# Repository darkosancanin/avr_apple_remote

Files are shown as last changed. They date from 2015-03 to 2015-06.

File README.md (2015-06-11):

### Overview 
ATtiny85 based micro controller project that replicates the functionality of an Apple remote control along with a simple hardware design for the remote control.

### Apple Remote/ NEC Protocol Overview
- The Apple Remote uses an NEC IR protocol which consists of a differential PPM encoding on a 1:3 duty cycle 38 kHz 950 nm infrared carrier.
- Remote commands are 32 bits long, in the format : remote id (8bits), command (8 bits), apple identifier (16 bits)
- The 32 bits of encoded data are sent between the leader and the stop bit (time in microseconds):
  - leader: 9000 on, 4500 off
  - 0 bit: 560 on, 1690 off
  - 1 bit: 560 on, 565 off
  - stop: 560 on
- More information at http://en.wikipedia.org/wiki/Apple_Remote and http://www.sbprojects.com/knowledge/ir/nec.php

### Implementation Overview
- This code uses a 50% duty cycle for the PWM (instead of the standard 1:3) for simplicity which still works.
- PWM is done using 'Clear Timer on Compare Match (CTC) Mode'. [Page 72] 11.7.2 describes CTC mode.
- Output is on 0C0A which is PB0. The internal clock is set to run at 8Mhz.
- No prescaler is used. @8Mhz 1 tick = .000000125 secs, 38khz is a cycle every .000026 secs. 
- This means there is 208 ticks required for a full cycle (.000026/.000000125). OCR0A is set to half of this at 104.
- This is half a full cycle, meaning it will be off for a half cycle, toggled due to COM0A0, and then on for a half cycle.
- We enable/disable PWM by enabling toggle on compare mode and then disconnecting OC0A and assuming normal port operation. [Page 78]
- The buttons are setup in a voltage ladder (http://en.wikipedia.org/wiki/Voltage_ladder). They are triggered via interrupts on PB4 and PB3 and each button is identified via a ADC conversion.
- The MCU is set to sleep in the main loop (using SLEEP_MODE_PWR_DOWN mode) and is only awoken using pin change interrupts.

### Button Voltage Ladder Values
Voltage ladder values (using 10 bit ADC resolution) on PB4
RIGHT:    0.00V @ 5V / 0.00V @ 3V / 0 (1.8K)
DOWN:     0.77V @ 5V / 0.46V @ 3V / 158 (330R)
MENU:     1.78V @ 5V / 1.08V @ 3V / 367 (680R)

Voltage ladder values (using 10 bit ADC resolution) on PB3
UP:      0.00V @ 5V / 0.00V @ 3V / 0 (1.8K)
LEFT:    0.77V @ 5V / 0.46V @ 3V / 158 (330R)
SELECT:  1.78V @ 5V / 1.08V @ 3V / 367 (680R)

### Schematic
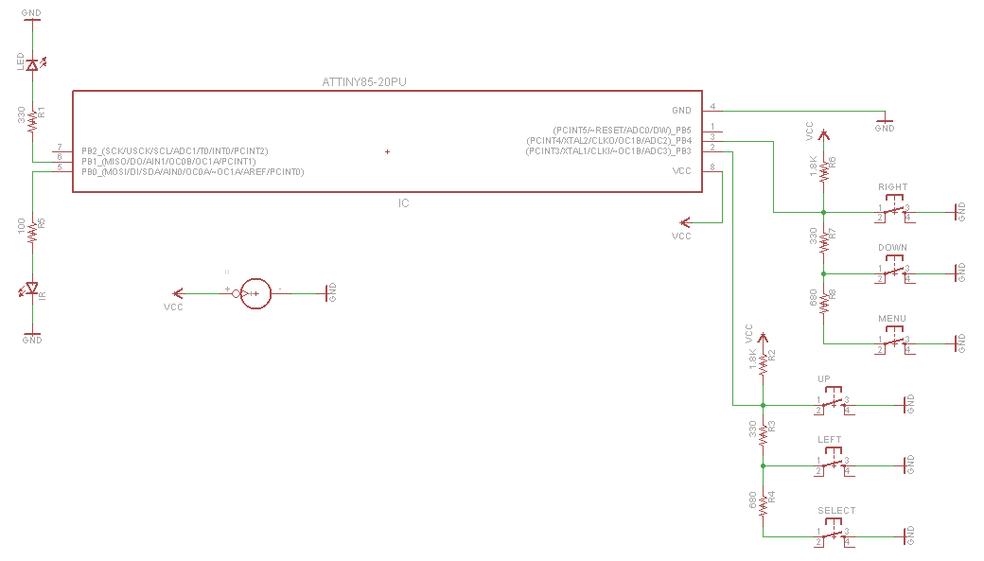
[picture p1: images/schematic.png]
Schematic


### Breadboard
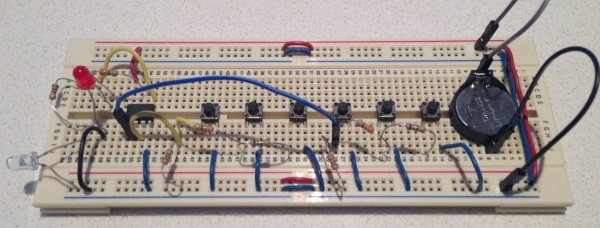
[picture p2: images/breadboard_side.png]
Side View


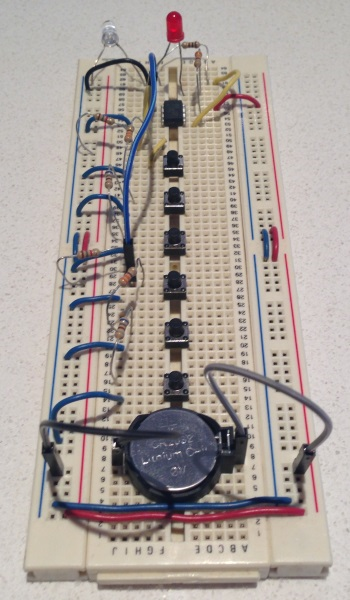
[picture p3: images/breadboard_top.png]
Top View


### PCB Layout
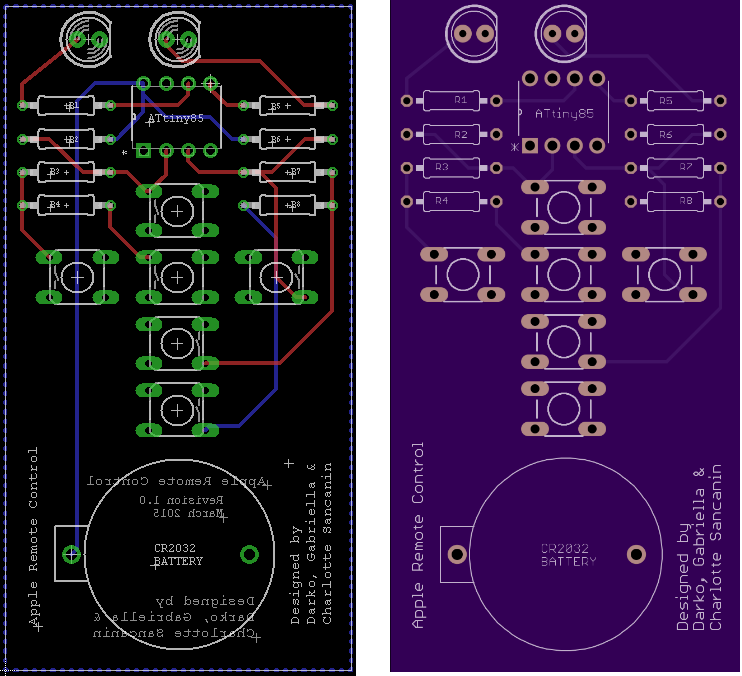
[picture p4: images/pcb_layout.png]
PCB Layout


### Final Product
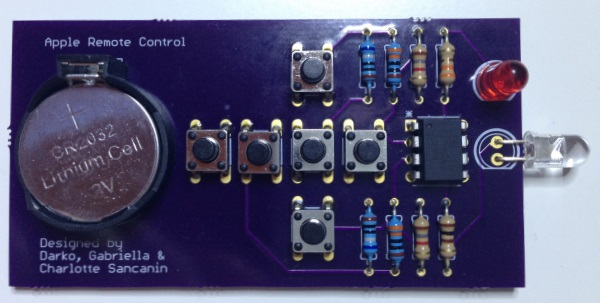
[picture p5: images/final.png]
Final Product


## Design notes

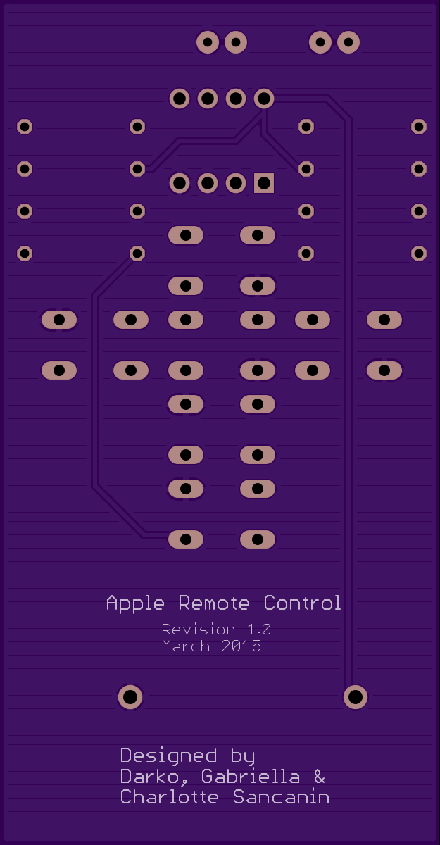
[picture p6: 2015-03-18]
pcb/back.png

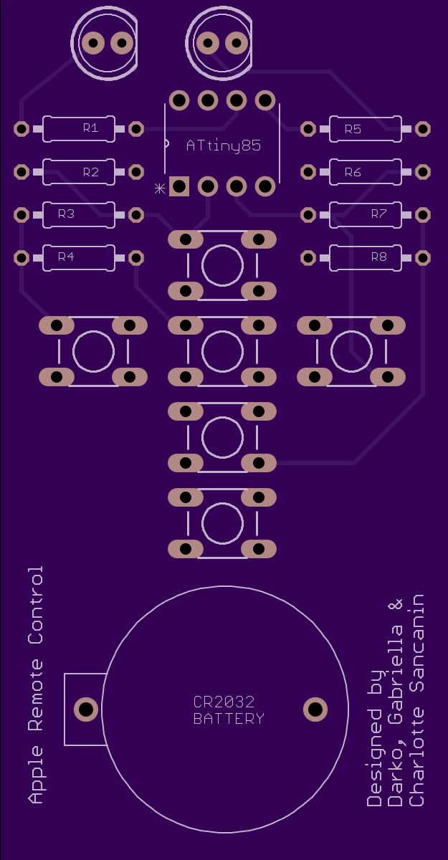
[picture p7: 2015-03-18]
pcb/front.png

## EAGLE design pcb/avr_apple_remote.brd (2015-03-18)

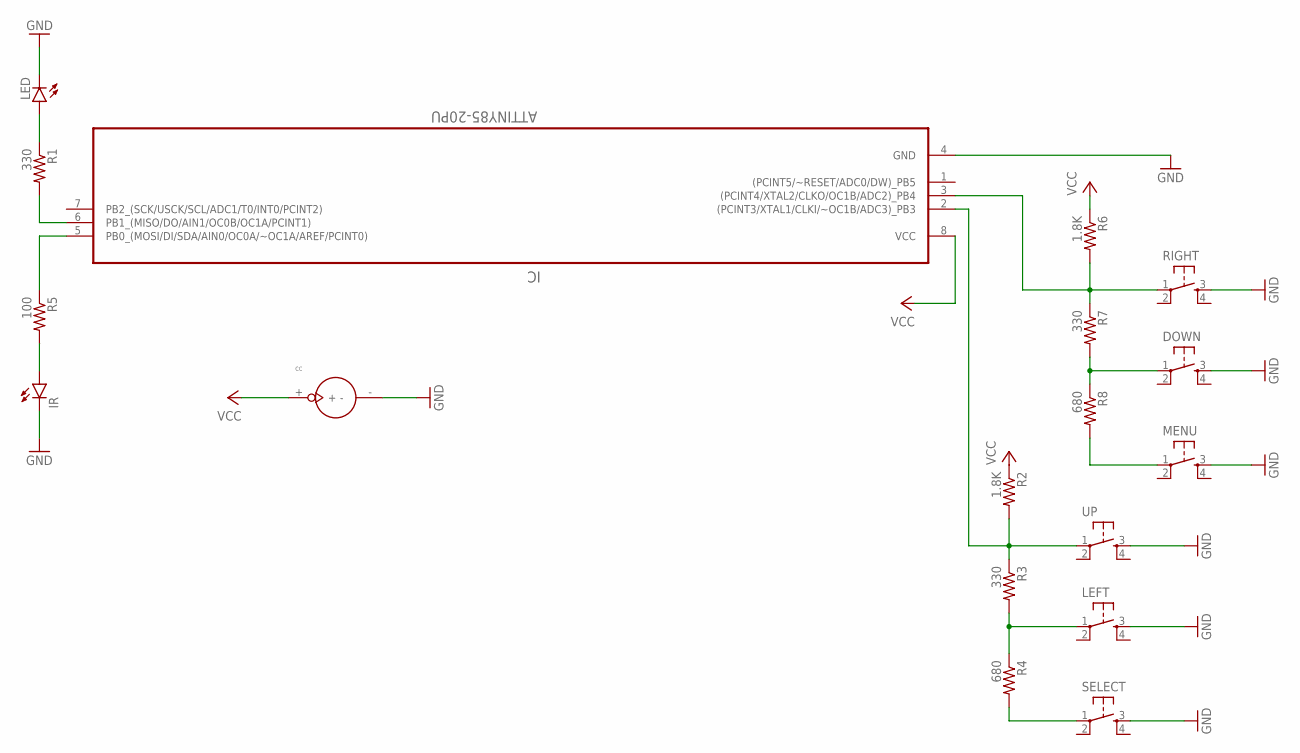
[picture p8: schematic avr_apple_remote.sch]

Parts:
CC: BATTERY_1236_C
DOWN: TACTILE-SWITCH-PTH; TAC-SWITCH-PTH
IC: ATTINY85-20PU; DIP254P762X533-8
IR: LED5MM
LED: LED5MM
LEFT: TACTILE-SWITCH-PTH; TAC-SWITCH-PTH
MENU: TACTILE-SWITCH-PTH; TAC-SWITCH-PTH
R1, R3, R7: 330; 0207/10
R2, R6: 1.8K; 0207/10
R4, R8: 680; 0207/10
R5: 100; 0207/10
RIGHT: TACTILE-SWITCH-PTH; TAC-SWITCH-PTH
SELECT: TACTILE-SWITCH-PTH; TAC-SWITCH-PTH
UP: TACTILE-SWITCH-PTH; TAC-SWITCH-PTH

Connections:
GND: CC.-, DOWN.3, IC.4 (GND), IR.K (C), LED.K (C), LEFT.3, MENU.3, RIGHT.3, SELECT.3, UP.3
unnamed: IC.3 ((PCINT4/XTAL2/CLKO/OC1B/ADC2)_PB4), R6.2, R7.1, RIGHT.1
unnamed: DOWN.1, R7.2, R8.1
unnamed: IC.2 ((PCINT3/XTAL1/CLKI/~OC1B/ADC3)_PB3), R2.2, R3.1, UP.1
unnamed: MENU.1, R8.2
unnamed: LEFT.1, R3.2, R4.1
unnamed: R4.2, SELECT.1
unnamed: IC.6 (PB1_(MISO/DO/AIN1/OC0B/OC1A/PCINT1)), R1.2
unnamed: LED.A, R1.1
unnamed: IC.5 (PB0_(MOSI/DI/SDA/AIN0/OC0A/~OC1A/AREF/P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), R5.1
unnamed: IR.A, R5.2
VCC: CC.+, IC.8 (VCC), R2.1, R6.1

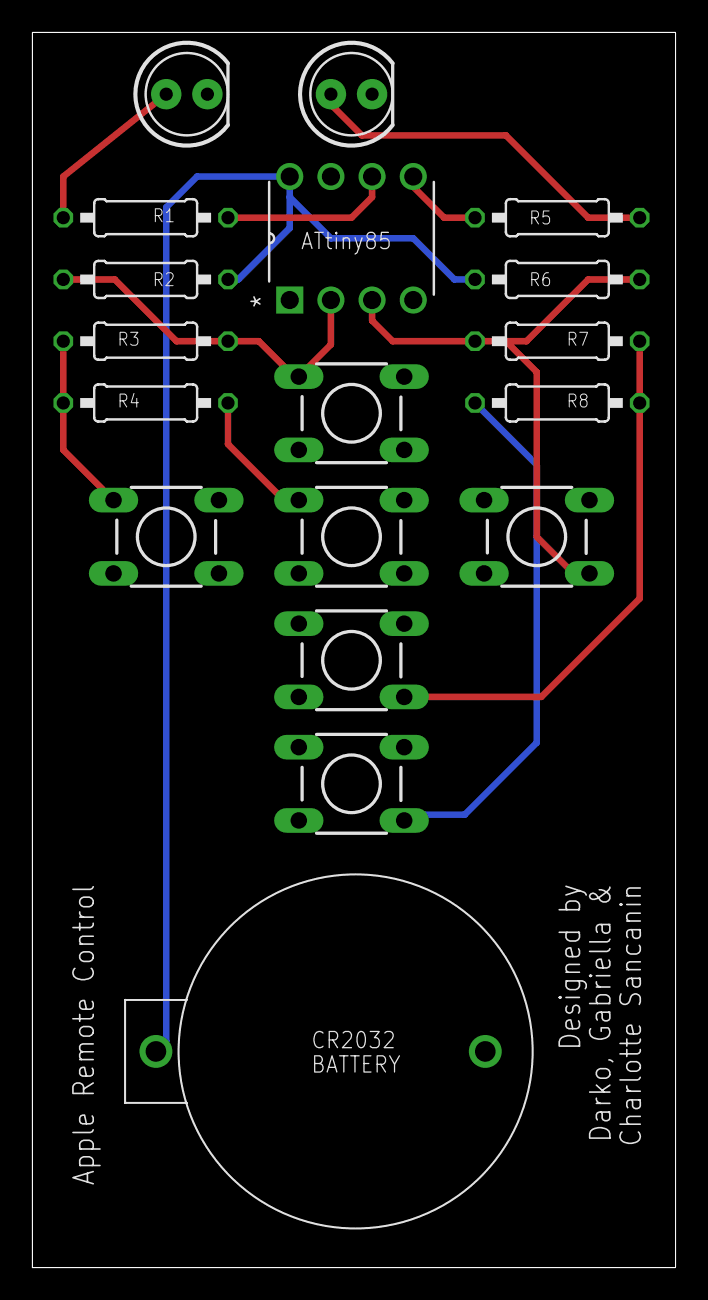
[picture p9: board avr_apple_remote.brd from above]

Board: 2 copper layers, 39.7 x 76.2 mm, 18 parts (0 on the bottom side), 12 nets.

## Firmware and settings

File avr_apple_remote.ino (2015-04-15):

#include <avr/interrupt.h>
#include <avr/io.h>
#include <avr/power.h>
#include <avr/sleep.h>
#include <inttypes.h>
#include <util/delay.h>

#define F_CPU 8000000UL // Set CPU frequency to 8Mhz

// Apple remote specific commands
#define APPLE_IDENTIFIER 0b0111100000010001
#define REMOTE_ID 0b00110001
#define MENU_COMMAND 0b11111100
#define PLAY_COMMAND 0b10100000
#define RIGHT_COMMAND 0b11111001
#define LEFT_COMMAND 0b11110110
#define UP_COMMAND 0b11110101
#define DOWN_COMMAND 0b11110011
#define SELECT_COMMAND 0b10100011

#define ENABLE_IR_LED  TCCR0A |= (1<<COM0A0); // Toggle OC0A/OC0B on Compare Match [Page 78];
#define DISABLE_IR_LED TCCR0A &= ~(1<<COM0A0); // Normal port operation, OC0A/OC0B disconnected [Page 78].

// ADC voltage values of each button on PB4
#define RIGHT_BUTTON_ADC_VALUE 0
#define DOWN_BUTTON_ADC_VALUE 158
#define MENU_BUTTON_ADC_VALUE 367
// ADC voltage values of each button on PB3
#define UP_BUTTON_ADC_VALUE 0
#define LEFT_BUTTON_ADC_VALUE 158
#define SELECT_BUTTON_ADC_VALUE 367
#define BUTTON_ADC_VARIANCE_ALLOWED 50 // Sets the variance allowed for the ADC conversion matches for the button presses

// Pulse length manual adjustment. Manual adjustment made if internal clock is not accurate. 
// This needs to be set back to standard values when a external crystal is used.
#define PULSE_LENGTH_9600 9200
#define PULSE_LENGTH_4500 4600
#define PULSE_LENGTH_560 570
#define PULSE_LENGTH_565 580
#define PULSE_LENGTH_1690 1750

int main(){
    DDRB |= (1 << DDB1) | (1 << DDB0); // Set pin PB0 as output. OC0A is on PB0. Setting PB1 as output for status LED.
    TCNT0 = 0; // Set the counter to 0
    TCCR0A = 0; // Initialize the Timer/Counter Control Register A
    TCCR0B = 0; // Initialize the Timer/Counter Control Register B

    TCCR0A |=(1 << WGM01); // Set Waveform Generation Mode to be Clear Timer on Compare Match (CTC) mode [Page 79]
    TCCR0B |= (1 << CS00); // Set the Prescaler to be 'clkI/O/(No prescaling)' [Page 80]
    OCR0A = 104; // Set the CTC compare value at which to toggle the OC0A/PB0 pin.
    
    // ADC Prescaler needs to be set so that the ADC input frequency is between 50 - 200kHz. [Page 125]
    ADCSRA |= (1 << ADPS1) | (1 << ADPS2); // Set the prescalar to be 64 which is 125kHz with a 8Mhz clock [Page 136] 
    ADCSRA |= (1 << ADEN); // Enable the ADC [Page 136]
    
    GIMSK |= (1 << PCIE); // Enable pin change interrupts on the General Interrupt Mask Register [Page 51]
    PCMSK |= (1 << PCINT4) | (1 << PCINT3); // Enable interrupts on PB3 and PB4 on the Pin Change Mask Register
    
    MCUCR |= (1 << SM1); // Sets the sleep mode to the most efficient 'Power-down'. [Page 35]
    MCUCR |= (1 << SE); // Sleep Enable. Must be enable the sleep instruction to be executed. [Page 37]
    WDTCR = 0; // Turn off the unused watchdog timer to reduce power consumption. [Page 37, 46]
    PRR &= ~(1 << PRUSI); // Power Reduction USI. Shuts down the unused USI module. [Page 38]
    
    sei(); // Enables interrupts
    
    while(1){
        ADCSRA &= ~(1 << ADEN); // Disable ADC, saves ~230uA, it gets re-enabled in the interrupt handler
        sleep_bod_disable(); // Soft disable the brown out detector, it automatically gets enabled on wake up [Page 35]
        sleep_cpu();
    }
    return 0;
}

// The NEC protocol that the remote uses expects commands in the following format (time in us): 
// leader: 9000 on, 4500 off
// 0 bit: 560 on, 1690 off
// 1 bit: 560 on, 565 off
// stop: 560 on
// commands are 32 bits long, in the format : remote id (8bits), command (8 bits), apple identifier (16 bits)
void send_command(uint8_t command){
    PORTB |= (1 << PORTB1); // Turn on status LED
  
    long data = REMOTE_ID;
    data = data << 8;
    data += command;
    data = data << 16;
    data += APPLE_IDENTIFIER;

    // Send leader pulse
    ENABLE_IR_LED;
    _delay_us(PULSE_LENGTH_9600);
    DISABLE_IR_LED;
    _delay_us(PULSE_LENGTH_4500);
    
    // Loop through the 32 bits and send 0 or 1 bit specific pulses
    int count = 0;
    while(count < 32){
        ENABLE_IR_LED;
        _delay_us(PULSE_LENGTH_560);
        DISABLE_IR_LED;
        if(data & 0b1){
            _delay_us(PULSE_LENGTH_565);
        }
        else{
            _delay_us(PULSE_LENGTH_1690);
        }
        // Right shift the data so we only have to compare the LSB
        data = data >> 1;
        count++;
    }
    
    // Send stop pulse
    ENABLE_IR_LED; 
    _delay_us(PULSE_LENGTH_560);
    DISABLE_IR_LED;
    
    PORTB &= ~(1 << PORTB1); // Turn off status LED
}

// Pin change interrupt handler
ISR(PCINT0_vect)
{
    ADCSRA |= (1<<ADEN); //Enable ADC

    if (!(PINB & (1 << PINB4))) { // If PB4 is low then check if its buttons 1 to 3.
        ADMUX = (1 << MUX1); // Connect PB4/ADC2 to the ADC [Page 135]
        ADCSRA |= (1 << ADSC); // Start the ADC measurement
        while (ADCSRA & (1 << ADSC)); // Wait until the conversion completes
        uint16_t adc_value = ADC; // Get the digital value
    
        if ( adc_value < (RIGHT_BUTTON_ADC_VALUE + BUTTON_ADC_VARIANCE_ALLOWED) ){
            send_command(RIGHT_COMMAND);
        } else if ( (adc_value > (DOWN_BUTTON_ADC_VALUE - BUTTON_ADC_VARIANCE_ALLOWED)) && (adc_value < (DOWN_BUTTON_ADC_VALUE + BUTTON_ADC_VARIANCE_ALLOWED)) ) {
            send_command(DOWN_COMMAND);
        } else if ( (adc_value > (MENU_BUTTON_ADC_VALUE - BUTTON_ADC_VARIANCE_ALLOWED)) && (adc_value < (MENU_BUTTON_ADC_VALUE + BUTTON_ADC_VARIANCE_ALLOWED)) ) {
            send_command(MENU_COMMAND);
        }
    } else { // Otherwise check if its button 4 to 6
        ADMUX = (1 << MUX1) | (1 << MUX0); // Connect PB3/ADC3 to the ADC [Page 135]
        ADCSRA |= (1 << ADSC); // Start the ADC measurement
        while (ADCSRA & (1 << ADSC)); // Wait until the conversion completes
        uint16_t adc_value = ADC; // Get the digital value
        
        if ( adc_value < (UP_BUTTON_ADC_VALUE + BUTTON_ADC_VARIANCE_ALLOWED) ) {
            send_command(UP_COMMAND);
        } else if ( (adc_value > (LEFT_BUTTON_ADC_VALUE - BUTTON_ADC_VARIANCE_ALLOWED)) && (adc_value < (LEFT_BUTTON_ADC_VALUE + BUTTON_ADC_VARIANCE_ALLOWED)) ) {
            send_command(LEFT_COMMAND);
        } else if ( (adc_value > (SELECT_BUTTON_ADC_VALUE - BUTTON_ADC_VARIANCE_ALLOWED)) && (adc_value < (SELECT_BUTTON_ADC_VALUE + BUTTON_ADC_VARIANCE_ALLOWED)) ) {
            send_command(SELECT_COMMAND);
        }
    }
    
    _delay_us(100000); // Delay in place to stop multiple unintended presses
}

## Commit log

2015-03-10 Updated to include ADC and match values for button presses.
2015-03-10 Reading the 10bit ADC value using the ADC register instead of ADCL and ADCH.
2015-03-12 Updated voltage ladder values to be used with 1.8K resistor instead of 2K.
2015-03-14 Moved buttons 4 and 5 to a different pin as they werent triggering a interrupt as their voltage was not below half VCC.
2015-03-14 Added select button.
2015-03-14 Added status LED.
2015-03-14 Removed pull up resistor test.
2015-03-14 Changed status LED to be on for the duration of the send command function.
2015-03-16 Put the chip into sleep mode when it is idle to minimize power consumption.
2015-03-17 Removed the enabling/disabling of interrupts on the ISR as I found out its automatically done.
2015-03-18 Updated some of the button voltage values after board layout reshuffle.
2015-03-18 Fixed status LED code.
    [avr_apple_remote.ino]
2015-03-18 Added PCB design.
    [avr_apple_remote.brd, avr_apple_remote.sch]
2015-03-18 Updated PCB design.
    [avr_apple_remote.brd]
2015-03-18 Updated PCB design with final version - revision 1.0.
    [avr_apple_remote.brd]

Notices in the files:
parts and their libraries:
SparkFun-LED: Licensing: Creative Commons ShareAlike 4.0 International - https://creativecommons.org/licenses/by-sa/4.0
